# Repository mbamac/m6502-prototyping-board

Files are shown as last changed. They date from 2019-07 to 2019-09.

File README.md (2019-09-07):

# m6502-prototyping-board

Prototyping board for 65c02 processor. Made with Eagle PCB 9.4.1

## License

[Creative Commons Attribution-NonCommercial-ShareAlike 4.0 International (CC BY-NC-SA 4.0)](https://creativecommons.org/licenses/by-nc-sa/4.0/)

## BOM
required:
* microprocessor W65C02S6TP - 1pcs
* static RAM CY62256LL-PC - 2 pcs
* eeprom AT28C64 - 1pcs
* quartz oscillator 1MHz-8MHz - 1pcs
* smd resistor 3.3K 1206 - 5pcs
* capacitor 100nF 0805 - 4pcs
* goldpins

optional:
* single inverter 74AHC1G04 in SOT23-5 package - 1pcs

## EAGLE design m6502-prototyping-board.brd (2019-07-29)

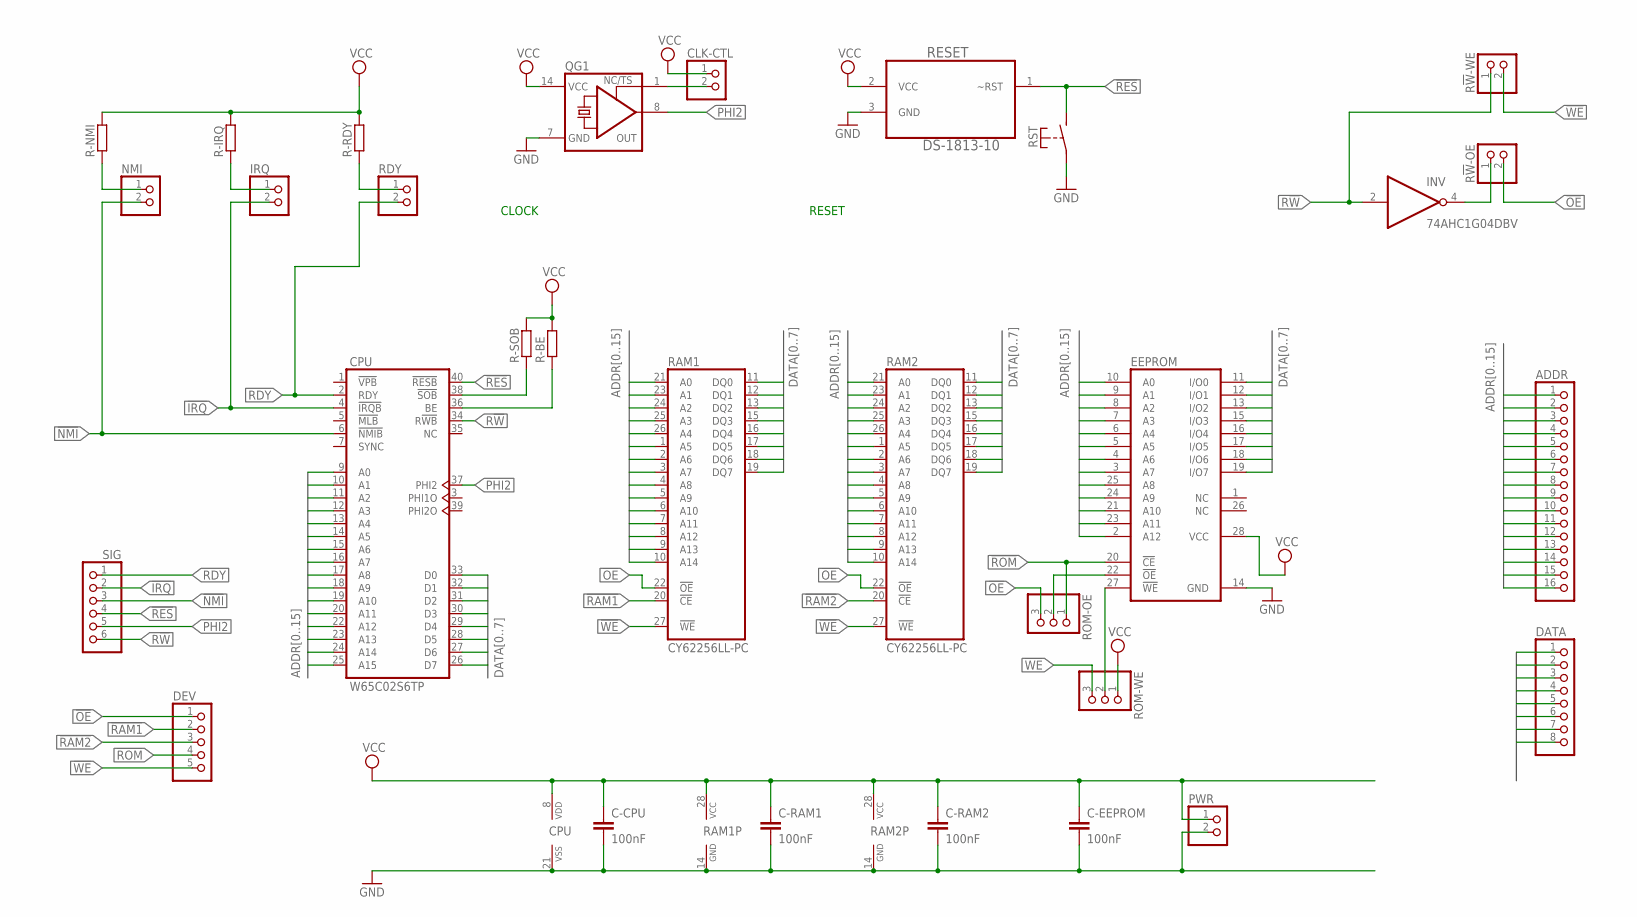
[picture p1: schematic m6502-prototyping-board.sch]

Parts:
ADDR: PINHD-1X16; 1X16
C-CPU: 100nF; C0805
C-EEPROM: 100nF; C0805
C-RAM1, C-RAM2: 100nF; C0805
CLK-CTL: PINHD-1X2; 1X02
CPU: W65C02S6TP; DIL40
DATA: PINHD-1X8; 1X08
DEV: PINHD-1X5; 1X05
EEPROM: 28C64C; DIL28-6
INV: 74AHC1G04DBV; SOT23-5
IRQ: PINHD-1X2; 1X02
NMI: PINHD-1X2; 1X02
PWR: PINHD-1X2; 1X02
QG1: XO-14; DIL14S
R!W!-OE: PINHD-1X2; 1X02
R!W!-WE: PINHD-1X2; 1X02
R-BE: R-EU_M1206; M1206
R-IRQ: R-EU_M1206; M1206
R-NMI: R-EU_M1206; M1206
R-RDY: R-EU_M1206; M1206
R-SOB: R-EU_M1206; M1206
RAM1, RAM2: CY62256LL-PC; DIL28-6
RDY: PINHD-1X2; 1X02
RESET: DS-1813-10; TO-92
ROM-OE: PINHD-1X3; 1X03
ROM-WE: PINHD-1X3; 1X03
RST: FSM
SIG: PINHD-1X6; 1X06

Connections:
!IRQ: CPU.4 (!IRQB), IRQ.2, SIG.2
!NMI: CPU.6 (!NMIB), NMI.2, SIG.3
!OE: DEV.1, R!W!-OE.2, RAM1.22 (!OE), RAM2.22 (!OE), ROM-OE.3
!RAM1: DEV.2, RAM1.20 (!CE)
!RAM2: DEV.3, RAM2.20 (!CE)
!RES: CPU.40 (!RESB), RESET.1 (~RST), RST.P$2 (S), SIG.4
!ROM: DEV.4, EEPROM.20 (!CE), ROM-OE.1
!WE: DEV.5, R!W!-WE.2, RAM1.27 (!WE), RAM2.27 (!WE), ROM-WE.3
ADDR0: ADDR.1, CPU.9 (A0), EEPROM.10 (A0), RAM1.10 (A14), RAM2.10 (A14)
ADDR1: ADDR.2, CPU.10 (A1), EEPROM.9 (A1), RAM1.9 (A13), RAM2.9 (A13)
ADDR2: ADDR.3, CPU.11 (A2), EEPROM.8 (A2), RAM1.8 (A12), RAM2.8 (A12)
ADDR3: ADDR.4, CPU.12 (A3), EEPROM.7 (A3), RAM1.7 (A11), RAM2.7 (A11)
ADDR4: ADDR.5, CPU.13 (A4), EEPROM.6 (A4), RAM1.6 (A10), RAM2.6 (A10)
ADDR5: ADDR.6, CPU.14 (A5), EEPROM.5 (A5), RAM1.5 (A9), RAM2.5 (A9)
ADDR6: ADDR.7, CPU.15 (A6), EEPROM.4 (A6), RAM1.4 (A8), RAM2.4 (A8)
ADDR7: ADDR.8, CPU.16 (A7), EEPROM.3 (A7), RAM1.3 (A7), RAM2.3 (A7)
ADDR8: ADDR.9, CPU.17 (A8), EEPROM.25 (A8), RAM1.25 (A3), RAM2.25 (A3)
ADDR9: ADDR.10, CPU.18 (A9), EEPROM.24 (A9), RAM1.24 (A2), RAM2.24 (A2)
ADDR10: ADDR.11, CPU.19 (A10), EEPROM.21 (A10), RAM1.21 (A0), RAM2.21 (A0)
ADDR11: ADDR.12, CPU.20 (A11), EEPROM.23 (A11), RAM1.23 (A1), RAM2.23 (A1)
ADDR12: ADDR.13, CPU.22 (A12), EEPROM.2 (A12), RAM1.2 (A6), RAM2.2 (A6)
ADDR13: ADDR.14, CPU.23 (A13), RAM1.26 (A4), RAM2.26 (A4)
ADDR14: ADDR.15, CPU.24 (A14), RAM1.1 (A5), RAM2.1 (A5)
ADDR15: ADDR.16, CPU.25 (A15)
DATA0: CPU.33 (D0), DATA.1, EEPROM.11 (I/O0), RAM1.11 (DQ0), RAM2.11 (DQ0)
DATA1: CPU.32 (D1), DATA.2, EEPROM.12 (I/O1), RAM1.12 (DQ1), RAM2.12 (DQ1)
DATA2: CPU.31 (D2), DATA.3, EEPROM.13 (I/O2), RAM1.13 (DQ2), RAM2.13 (DQ2)
DATA3: CPU.30 (D3), DATA.4, EEPROM.15 (I/O3), RAM1.15 (DQ3), RAM2.15 (DQ3)
DATA4: CPU.29 (D4), DATA.5, EEPROM.16 (I/O4), RAM1.16 (DQ4), RAM2.16 (DQ4)
DATA5: CPU.28 (D5), DATA.6, EEPROM.17 (I/O5), RAM1.17 (DQ5), RAM2.17 (DQ5)
DATA6: CPU.27 (D6), DATA.7, EEPROM.18 (I/O6), RAM1.18 (DQ6), RAM2.18 (DQ6)
DATA7: CPU.26 (D7), DATA.8, EEPROM.19 (I/O7), RAM1.19 (DQ7), RAM2.19 (DQ7)
GND: C-CPU.2, C-EEPROM.2, C-RAM1.2, C-RAM2.2, CPU.21 (VSS), EEPROM.14 (GND), INV.3 (GND), PWR.2, QG1.7 (GND), RAM1.14 (GND), RAM2.14 (GND), RESET.3 (GND), RST.P$1
unnamed: NMI.1, R-NMI.1
unnamed: IRQ.1, R-IRQ.1
unnamed: EEPROM.27 (!WE), ROM-WE.2
unnamed: CPU.38 (!SOB), R-SOB.1
unnamed: EEPROM.22 (!OE), ROM-OE.2
unnamed: CPU.36 (BE), R-BE.1
unnamed: R-RDY.1, RDY.1
unnamed: CLK-CTL.2, QG1.1 (TS)
unnamed: INV.4 (O), R!W!-OE.1
PHI2: CPU.37 (PHI2), QG1.8 (OUT), SIG.5
R!W: CPU.34 (R!WB), INV.2 (I), R!W!-WE.1, SIG.6
RDY: CPU.2 (RDY), RDY.2, SIG.1
VCC: C-CPU.1, C-EEPROM.1, C-RAM1.1, C-RAM2.1, CLK-CTL.1, CPU.8 (VDD), EEPROM.28 (VCC), INV.5 (VCC), PWR.1, QG1.14 (VCC), R-BE.2, R-IRQ.2, R-NMI.2, R-RDY.2, R-SOB.2, RAM1.28 (VCC), RAM2.28 (VCC), RESET.2 (VCC), ROM-WE.1

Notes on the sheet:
CLOCK
RESET

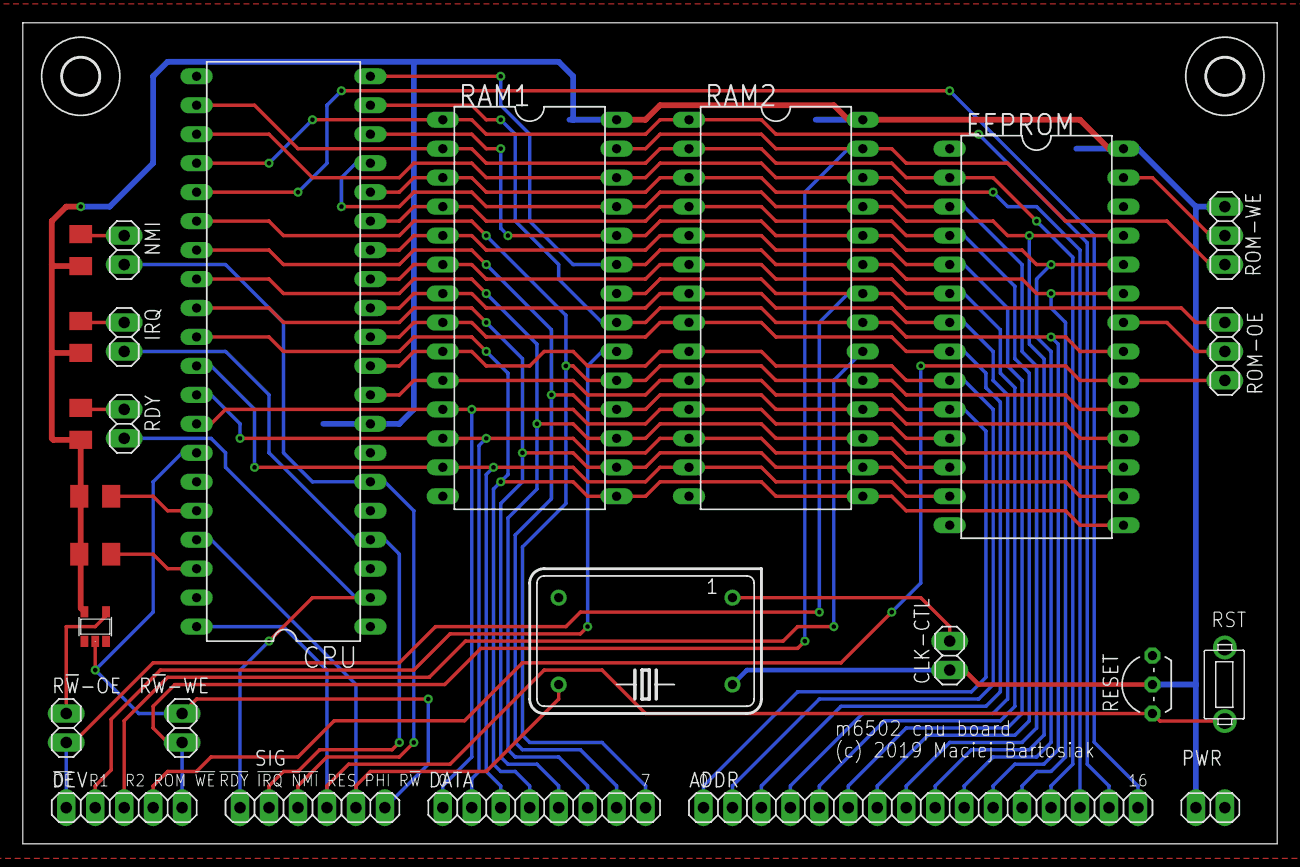
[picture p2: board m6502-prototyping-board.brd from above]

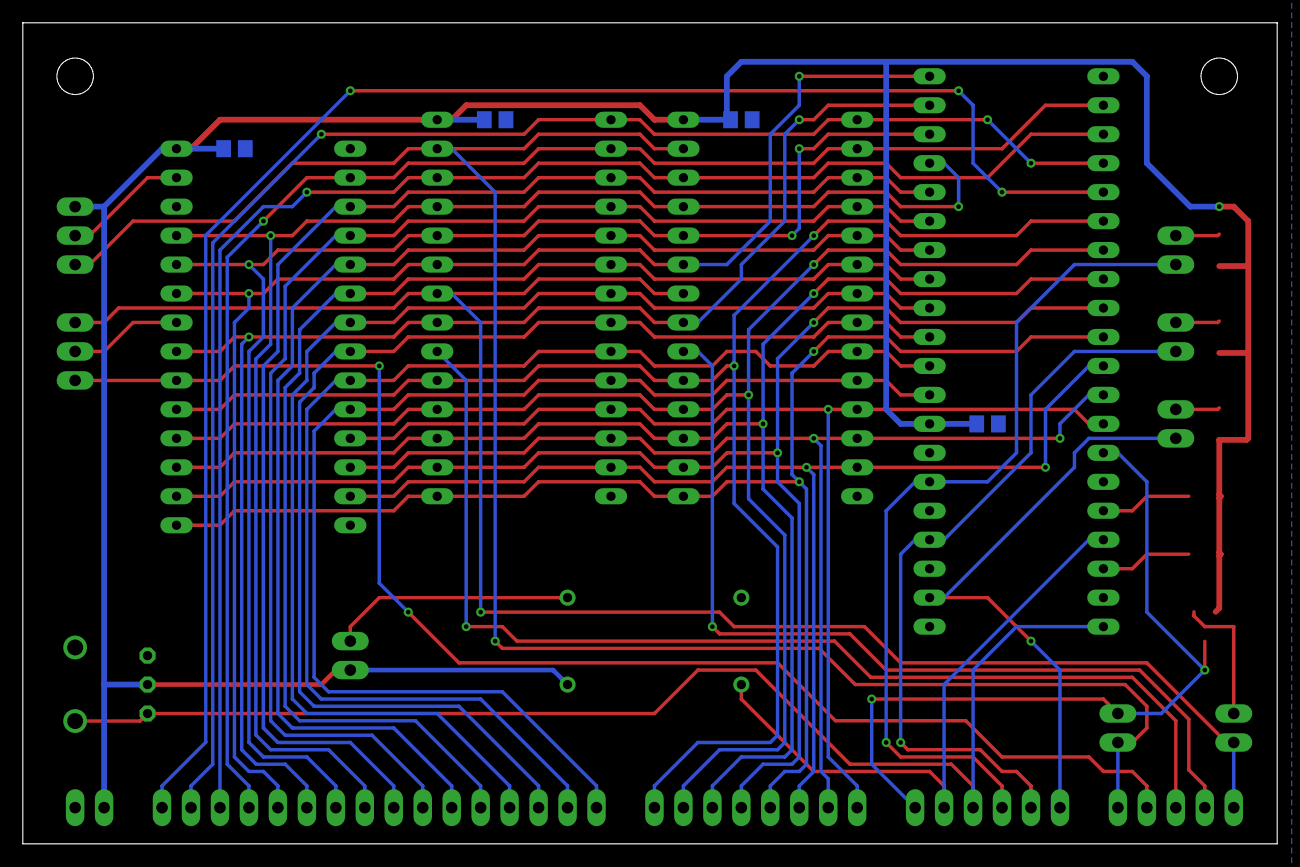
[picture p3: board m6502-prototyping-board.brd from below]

Board: 2 copper layers, 110.0 x 72.0 mm, 32 parts (4 on the bottom side), 46 nets.

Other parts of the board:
U$1, U$2: 3,2

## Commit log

2019-07-24 Update README.md
    added BOM
2019-07-29 removed RDY connection to eeprom
    [m6502-prototyping-board.brd, m6502-prototyping-board.sch]

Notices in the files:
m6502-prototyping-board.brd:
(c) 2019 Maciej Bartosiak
